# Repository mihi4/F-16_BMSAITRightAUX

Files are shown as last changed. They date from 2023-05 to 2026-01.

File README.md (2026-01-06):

# !!! ATTENTION !!!!
## I don't use BMSAIT anymore, so this repository is quite outdated and never got into my sim as it is

# BMSAIT Right Aux Controller
* Microcontroller: Arduino Nano

## Hardware controlled
- PFD
- CAUTION PANEL
- COMPASS
- FUEL QTY Gauge
- HYD PRESS Gauges
- EPU FUEL Gauge
- CABIN PRESS Gauge
- ~~(LIQUID FUEL Gauge)~~
- SIM1 Panel (??? 3 LEDs of MM5451 available)
## Pinmapping
* PFD: 
  * Serial Display  
    (Old DED, 2 pins, softwareSerial) D2,D3
* CAUTION PANEL:
  * 1 MM5451  
    (2 pins) D4,D5
* HYD PRESS:
  * 2 Servos  
    (2 pins) D6,D7
* FUEL QTY:
  * 2 servos  
    (2 pins) D8,D9
  * MAX7219 5 digit 7seg display  
    (3 pins) D10,D11,D12
* AX1201728SG (7 pins), D13-A5
  * COMPASS: 1 X27  
    (2 pins)
  * CABIN PRESS: 1 X27  
    (2 pins)
  * EPU FUEL: 1 X27  
    (2 pins)  
* Input for compass seroizing sensor (1 pin) A6  
* Input for compass seroizing button (1 pin) A7

## !!! Use those files at your own risk !!!

All the files are free to use under the GNUGPLv3

If you find those files useful and would like to support me with an icecream, coffee or pizza, you can use paypal.me to do so ;)  
[Paypal.me](https://paypal.me/MichiHirczy)

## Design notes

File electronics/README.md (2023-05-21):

# KiCAD files and other files related to electronics hardware

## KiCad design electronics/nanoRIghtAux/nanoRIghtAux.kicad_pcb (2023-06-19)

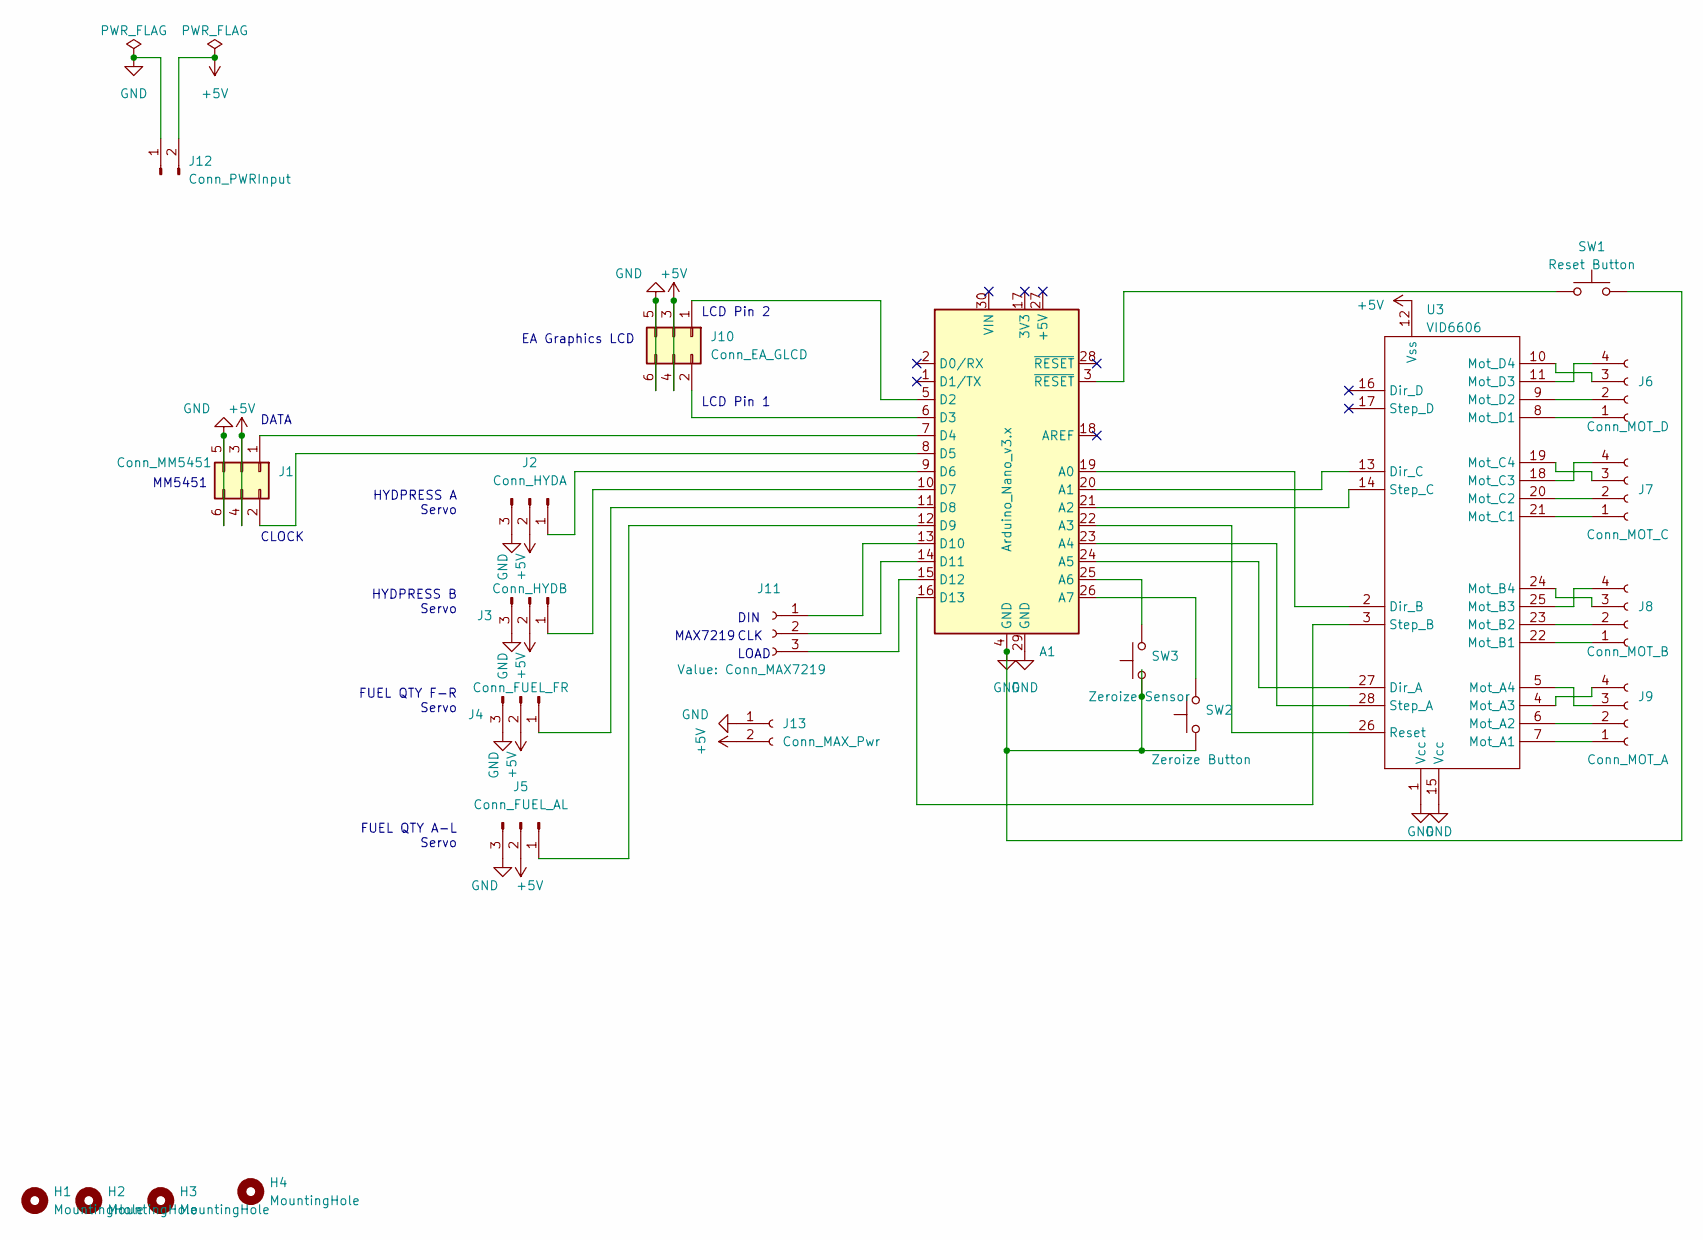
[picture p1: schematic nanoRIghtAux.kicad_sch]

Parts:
A1: Arduino_Nano_v3.x; Arduino_Nano
H1, H2, H3, H4: MountingHole; MountingHole_3.5mm
J1: Conn_MM5451; PinHeader_2x03_P2.54mm_Vertical
J2: Conn_HYDA; PinHeader_1x03_P2.54mm_Vertical
J3: Conn_HYDB; PinHeader_1x03_P2.54mm_Vertical
J4: Conn_FUEL_FR; PinHeader_1x03_P2.54mm_Vertical
J5: Conn_FUEL_AL; PinHeader_1x03_P2.54mm_Vertical
J6: Conn_MOT_D; PinHeader_1x04_P2.54mm_Vertical
J7: Conn_MOT_C; PinHeader_1x04_P2.54mm_Vertical
J8: Conn_MOT_B; PinHeader_1x04_P2.54mm_Vertical
J9: Conn_MOT_A; PinHeader_1x04_P2.54mm_Vertical
J10: Conn_EA_GLCD; PinHeader_2x03_P2.54mm_Vertical
J11: Conn_MAX7219; PinSocket_1x03_P2.54mm_Vertical
J12: Conn_PWRInput; PinHeader_1x02_P2.54mm_Vertical
J13: Conn_MAX_Pwr; PinSocket_1x02_P2.54mm_Vertical
SW1: Reset Button; PinHeader_1x02_P2.54mm_Vertical
SW2: Zeroize Button; PinHeader_1x02_P2.54mm_Vertical
SW3: Zeroize Sensor; PinHeader_1x02_P2.54mm_Vertical
U3: VID6606; DIP-28_W15.24mm

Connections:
+5V: J1.3, J1.4, J2.2, J3.2, J4.2, J5.2, J10.3, J10.4, J12.2, J13.2, U3.12 (Vss)
GND: A1.4 (GND), A1.29 (GND), J1.5, J1.6, J2.3, J3.3, J4.3, J5.3, J10.5, J10.6, J12.1, J13.1, SW1.2, SW2.1, SW3.1, U3.1 (Vcc), U3.15 (Vcc)
unnamed: A1.19 (A0), U3.2 (Dir_B)
unnamed: A1.20 (A1), U3.13 (Dir_C)
unnamed: A1.21 (A2), U3.14 (Step_C)
unnamed: A1.22 (A3), U3.26 (Reset)
unnamed: A1.23 (A4), U3.28 (Step_A)
unnamed: A1.24 (A5), U3.27 (Dir_A)
unnamed: A1.25 (A6), SW3.2
unnamed: A1.26 (A7), SW2.2
unnamed: A1.5 (D2), J10.1
unnamed: A1.6 (D3), J10.2
unnamed: A1.7 (D4), J1.1
unnamed: A1.8 (D5), J1.2
unnamed: A1.9 (D6), J2.1
unnamed: A1.10 (D7), J3.1
unnamed: A1.11 (D8), J4.1
unnamed: A1.12 (D9), J5.1
unnamed: A1.13 (D10), J11.1
unnamed: A1.14 (D11), J11.2
unnamed: A1.15 (D12), J11.3
unnamed: A1.16 (D13), U3.3 (Step_B)
unnamed: A1.3 (~RESET), SW1.1
unnamed: J6.1, U3.8 (Mot_D1)
unnamed: J6.2, U3.9 (Mot_D2)
unnamed: J6.3, U3.10 (Mot_D4)
unnamed: J6.4, U3.11 (Mot_D3)
unnamed: J7.1, U3.21 (Mot_C1)
unnamed: J7.2, U3.20 (Mot_C2)
unnamed: J7.3, U3.19 (Mot_C4)
unnamed: J7.4, U3.18 (Mot_C3)
unnamed: J8.1, U3.22 (Mot_B1)
unnamed: J8.2, U3.23 (Mot_B2)
unnamed: J8.3, U3.24 (Mot_B4)
unnamed: J8.4, U3.25 (Mot_B3)
unnamed: J9.1, U3.7 (Mot_A1)
unnamed: J9.2, U3.6 (Mot_A2)
unnamed: J9.3, U3.5 (Mot_A4)
unnamed: J9.4, U3.4 (Mot_A3)

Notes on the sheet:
LOAD
HYDPRESS A Servo
HYDPRESS B Servo
FUEL QTY F-R Servo
CLK
CLOCK
MAX7219
FUEL QTY A-L Servo
DATA
LCD Pin 2
LCD Pin 1
EA Graphics LCD
MM5451
DIN

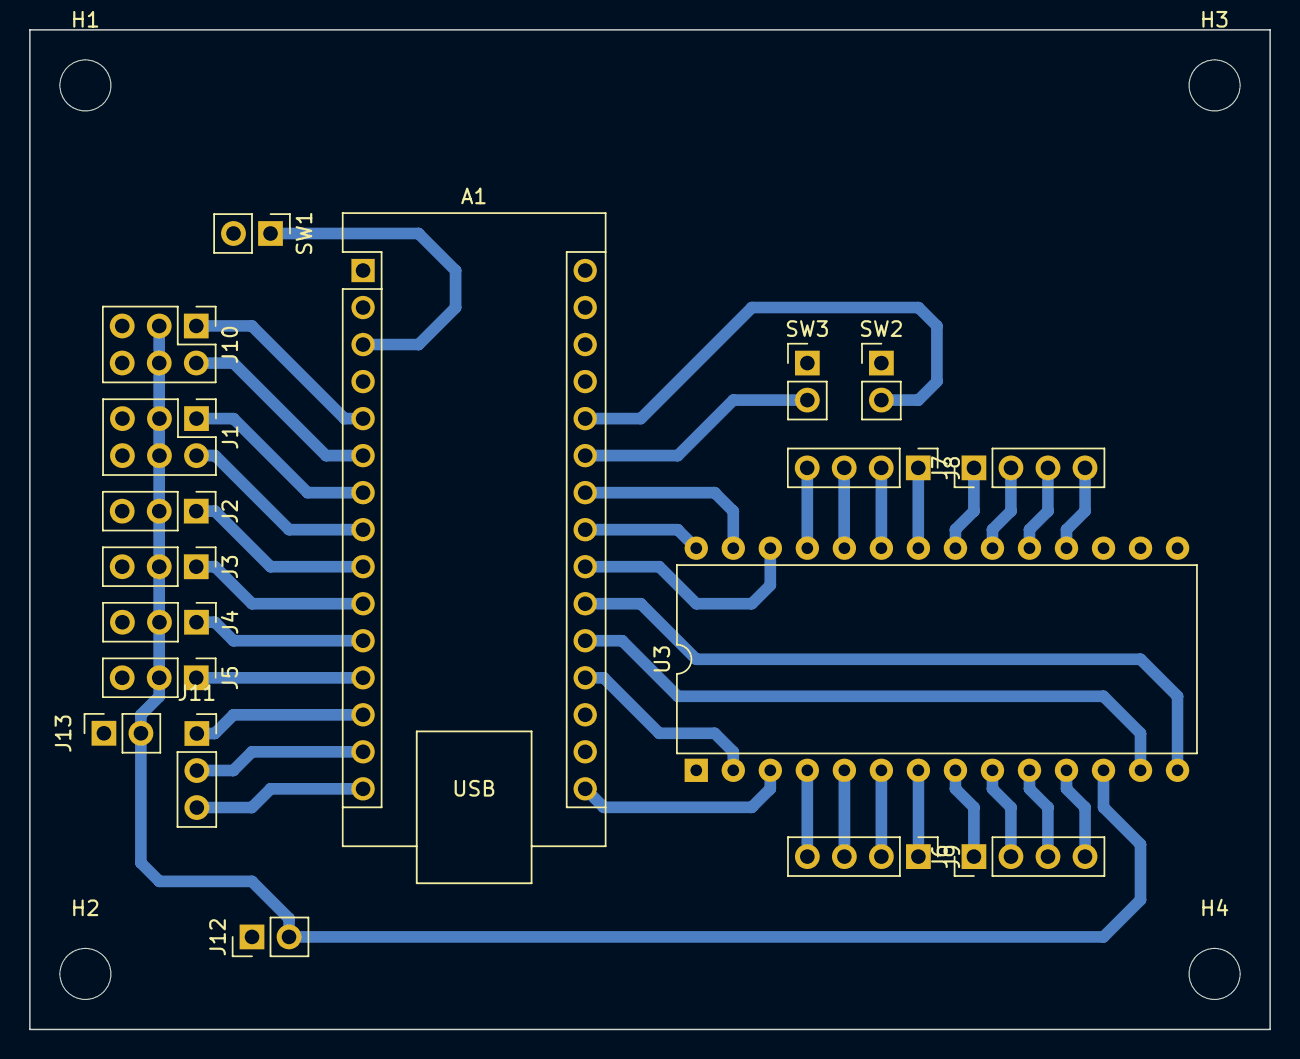
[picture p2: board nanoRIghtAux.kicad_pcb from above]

Board: 2 copper layers, 85.1 x 68.6 mm, 22 parts (0 on the bottom side), 39 nets.

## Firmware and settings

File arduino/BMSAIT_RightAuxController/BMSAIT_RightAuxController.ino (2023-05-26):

// Arduino sketch to send/recieve data from the Falcon BMS Shared Memory via the BMS-Arduino Interface Tool and control devices in home cockpits
// Version: 1.3.13   30.3.22
// Robin "Hummer" Bruns


//basic settings
  #include <Arduino.h>
  #include <OneButton.h>

  #define DATENLAENGE 8       // maximum length of a data set
  #define MESSAGEBEGIN 255    // this byte marks the beginning of a new message from the Windows app
  #define HANDSHAKE 128       // this byte marks an identification request from the Windows app
  #define SWITCHPOSITION 150  // this byte marks a request to send current switch positions
  #define CALIBRATE 160       // this byte marks a request to reset motors to inital position
  #define ZEROIZE   161       // this byte marks a request to fast zeroize motors 
  #define STARTPULL 170       // this byte marks a request to start the PULL logic on the arduino
  #define ENDPULL 180         // this byte marks a request to end the PULL logic on the arduino
  #define TESTON  190         // activates testmode
  #define READBACKON 191      // activates testmode with readback of data variables
  #define TESTOFF 200         // deactivates testmode
  #define VAR_BEGIN '<'       // char to mark the begin of the actual data
  #define VAR_ENDE '>'        // char to mark the end of the actual data
  #define TYP_ANFANG '{'      // char to mark the begin of the type definition in a message string
  #define TYP_ENDE '}'        // char to mark the begin of the type definition in a message string
  
//Function headers
  void ReadData();
  void UpdateInput();
  void UpdateOutput();
  void PullRequest(byte v);
  void ReadResponse();     
  void DebugReadback(byte posID);
  void SendSysCommand(const char text[]); 
  void SendMessage(const char message[], byte option);
  void ResetMotors();
  void FastUpdate();
  bool CheckForSysCommand(byte SysCmd);
  
  
  
//Struct definitions
  typedef struct //data field structure for storage of data variables
  {
    char bezeichnung[6];            //short description (max. 5 characters)
    char ID[5];                     //only required for PULL-operation. The ID for this data from "BMSAIT-Variablen.csv". this will tell the windows app what kind of data you are requesting
    char format;                    //only required for PULL-operation. Data type according to  "BMSAIT-Variablen.csv" (y=byte, i=integer, f=float, s=string, b=bool, 1=Byte Array, 2=Int Array, 3=string Array, 4=float Array) 
    byte typ;                       //indicates the type of device that will be used to output his data (10: LED, 20: LCD, 30: 7-Segment MAX7219, 40: Servomotor)
    byte target;                    //this byte links the variable to a specific device (i.e. PIN for LED output, the adress for motors on a pwm shield or to differentiate between multiple devices within one module)
    byte ref2;                      //the use of reference byte depends on the output type. Ref2 can set the line on LCD displays
    byte ref3;                      //the use of reference byte depends on the output type. Ref3 can set the length if a data value to display on LCD or 7-segment displays
    byte ref4;                      //the use of reference byte depends on the output type. Ref4 can set the position of data on LCD / 7Segment displays. if set, the data will be offset by this number of characters
    byte ref5;                      //the use of reference byte depends on the output type. Ref5 can mark the position of the decimal point on 7-Segment displays
    char request[10];               //precompiled pull request message
    char wert[DATENLAENGE];         //contains the current value
  } Datenfeld;

  typedef struct              //container to store incoming data from the Windows app
  {
    byte varNr;                     //position for this data in the local file container 
    char typ;                       //file format of this data 
    char wert[DATENLAENGE];         //data
  } Uebertragung;
  Uebertragung neuer_wert;

//Load user settings
  #include "BMSAIT_UserConfig.h"   //load the user settings 

//Global variables
  byte inputByte_0;           //container for incoming serial message
  byte inputByte_1;           //container for incoming serial message
  byte state =0;              //marker to memorize the current position in a message string
  byte Uebertragung_pos=0;    //counts how many chars have already been read from an incoming data stram. Used to prevent an overflow of data variables. 
  bool debugmode=false;        //debugmode on/off
  bool readbackmode=false;        //Readbackmode on/off
  unsigned long lastInput =0; //last successful transmission  
    
  int compassOffset = 0;
  
  #ifdef DUE_NATIVE
    #define SERIALCOM SerialUSB   //enable communication over the native port of the DUE
  #else
    #define SERIALCOM Serial      //standard serial connection
  #endif
  
//settings for PULL logic
  bool pull= false;           //flag that defines wether to use push or pull logic (true=pull ; false=push). Can be switched by commands of the F4SMExporter App
  long lastPoll=0;            //timestamp of the last data request during pull logic
  byte last_request=99;        //marker for the last variable that was requested via pull logic in the last loop 
//settings for PULL logic



//button matrix settings
#ifdef ButtonMatrix               
  #include "BMSAIT_Buttonmatrix.h"
#endif  

//analog axis settings
#ifdef AnalogAxis 
  #include "BMSAIT_Analogachse.h"
#endif 

//LED settings
#ifdef LED                             
  #include "BMSAIT_LED.h"
#endif

//LED matrix settings
#ifdef LEDMatrix                             
  #include "BMSAIT_LEDMatrix.h"
#endif

//LED MM5451 settings
#ifdef LED_MM5451
  #include "BMSAIT_LED_MM5451.h"
#endif

//LCD settings
#ifdef LCD                              
  #include "BMSAIT_LCD.h"
#endif    

//7Segment settings MAX 7219 tube
#ifdef SSegMAX7219                              
  #include "BMSAIT_SSegMAX7219.h"
#endif                                

//7Segment settings TM1637 tube
#ifdef SSegTM1637                            
  #include "BMSAIT_SSegTM1637.h"
#endif  

//DotMatrix settings SLx2016 tube
#ifdef SLx2016                            
  #include "BMSAIT_SLx2016.h"
#endif  

//Servo settings
#ifdef ServoMotor                       
  #include "BMSAIT_Servo.h"               
#endif                            

//PWM Shield for Servos settings
#ifdef ServoPWM                       
  #include "BMSAIT_ServoPWMShield.h"               
#endif  

//Steppermotor settings
#ifdef StepperBYJ                  
  #include "BMSAIT_Stepper28BYJ48.h"
#endif                                

//Steppermotor settings
#ifdef StepperX27                 
  #include "BMSAIT_StepperX27.h"
#endif  

//Steppermotor ControllerBoard settings
#ifdef StepperVID                   
  #include "BMSAIT_StepperVID.h"
#endif  

//Compass setting
#ifdef CompassX27                  
  #include "BMSAIT_CompassX27.h"
#endif  

//Compass setting
#ifdef AltimeterX27                  
  #include "BMSAIT_AltimeterX27.h"
  #include "AltimeterInternal.h"
#endif  

//switch and signal settings
#ifdef Switches                
  #include "BMSAIT_Switches.h" 
#endif  
 

//motor poti settings
#ifdef MotorPoti 
  #include "BMSAIT_MotorPoti.h"
#endif 

#ifdef OLED
  #include "BMSAIT_OLED.h"
#endif

#ifdef SpeedBrake                             
  #include "BMSAIT_SBI.h"
#endif

#ifdef FuelFlowIndicator
  #include "BMSAIT_FF.h"
#endif

#ifdef DED_PFL                             
  #include "BMSAIT_DED_PFL.h"
#endif

#ifdef Lighting                             
  #include "BMSAIT_Lighting.h"
#endif

//rotary encoders
#ifdef RotEncoder               
  #include "BMSAIT_Encoder.h"
#endif  


//example how to add your own project to this sketch. 
#ifdef NewDevice                
  #include "BMSAIT_Placeholder.h"
#endif  






//********************
//Main Program
//********************

///Setup of BMSAIT
void setup()
{
  SERIALCOM.begin(BAUDRATE);
	
  #ifdef LED                            //LEDs setup begin
    SetupLED();
  #endif                                //LEDs setup end
  
  #ifdef LEDMatrix                      //LEDMatrix setup begin
    SetupLEDMatrix();
  #endif                                //LEDMatrix setup end

  #ifdef LED_MM5451                      //LED MM5451 setup begin
    SetupLED_MM5451();
  #endif                                //LED MM5451 setup end
 
  #ifdef LCD                            //LCD setup begin
   SetupLCD();
  #endif                                //LCD setup end
  
  #ifdef SSegMAX7219                    //7-segment-display MAX7219 setup begin
   SetupMax7219();
  #endif                                //7-segment-display MAX7219 setup end

  #ifdef SSegTM1637                     //7-segment-display TM1637 setup begin
   SetupTM1637();
  #endif                                //7-segment-display TM1637 setup end

  #ifdef SLx2016                        //Dotmatrix-display SLx2016 setup begin
   SetupSLx2016();
  #endif                                //Dotmatrix-display SLx2016 setup end
                              
  #ifdef ServoMotor                     //servo setup begin
   SetupServo();
  #endif                                //servo setup end
  
  #ifdef ServoPWM                       //servo PWM shield setup begin
    SetupServoPWM();          
  #endif                                //servo PWM shield setup end
    
  #ifdef StepperBYJ                     //stepper setup begin
   //SetupStepperBYJ();
  #endif                                //stepper setup end

  #ifdef StepperX27                     //stepper setup begin
   SetupStepperX27();
  #endif                                //stepper setup end
  
  #ifdef StepperVID                     //stepper on controller board setup begin
   SetupStepperVID();
  #endif                                //stepper setup end

  #ifdef CompassX27                     //Compass setup start
   SetupCompassX27();
  #endif                                //Compass setup end

  #ifdef AltimeterX27                   //Altimeter setup start
   SetupAltimeterX27();
   SetupAltimeterKnob();
  #endif                                //Altimeter setup end

  #ifdef MotorPoti                      //MotorPoti setup begin
    SetupMotorPoti();
  #endif                                //MotorPoti setup end
  
  #ifdef OLED                           //OLED setup begin
    SetupOLED();
  #endif                                //OLED setup end
  
  #ifdef SpeedBrake                     //SBI setup begin
    SetupSBI();
  #endif                                //SBI setup end
  
  #ifdef FuelFlowIndicator              //FFI setup begin
   SetupFFI();
  #endif                                //FFI setup end
  
  #ifdef DED_PFL                        //DED setup begin
    SetupDED();
  #endif                                //DED setup end

  #ifdef Switches                       //Input controller setup begin
   SetupSwitches();
  #endif                                //Input controller setup end
  
  #ifdef ButtonMatrix                   //Buttonmatrix setup begin
   SetupButtonMatrix();
  #endif                                //Buttonmatrix setup end
  
  #ifdef RotEncoder                     //Rotary encoder setup begin
   SetupEncoder();
  #endif                                //Rotary encoder setup end

  #ifdef AnalogAxis                     //Analog axis setup begin
   SetupAnalog();
  #endif                                //Analog axis setup end  

  #ifdef Lighting                       //Lighting axis setup begin     
   SetupLighting();
  #endif                                //Lighting axis setup end 

  #ifdef NewDevice                      //Example. Use this placeholder to activate your own projects
    SetupNewDevice();
  #endif                                //Example end

 //precompile pull messages
  char pos[2]={0,0};
  char nachricht[10]={0};
  for (byte var=0;var<VARIABLENANZAHL;var++)
  {                                          
    itoa(var,pos,10);  //write data container position as character
    if (var<10) 
    {
      nachricht[0]='0'; 
      nachricht[1]=pos[0];
    }
    else 
    {
      nachricht[0]=pos[0]; 
      nachricht[1]=pos[1];
    }
    nachricht[2]=',';
    nachricht[3]=datenfeld[var].format;  //add the variable type
    nachricht[4]=',';
    for (byte lauf=0;lauf<4;lauf++)
      {nachricht[5+lauf]=datenfeld[var].ID[lauf];} //add the variable ID
    nachricht[9]='\0';
    strcpy(datenfeld[var].request,nachricht);
	SendMessage(datenfeld[var].request,1);
  }
  SendMessage("SETUP DONE",1);
  delay(1000);
}

/// Main loop
void loop()              
{	
  FastUpdate();
  delay(1);
  FastUpdate();
  ReadData();  //get new data from PC
  FastUpdate();
  UpdateOutput(); //update outputs (LEDs, motors, displays)  
  FastUpdate();
  UpdateInput(false); //check input devices (switches, buttons)
  FastUpdate();
}

//********************
//Functions
//********************

/// reset motor positions to default values
void ResetMotors(bool full)
{
#ifdef ServoMotor                       
  Servo_Zeroize(full);            
#endif                            

#ifdef ServoPWM                       
  ServoPWM_Zeroize(full);              
#endif  

#ifdef StepperVID
  StepperVID_Zeroize(full);   
#endif
 
#ifdef StepperX27
  StepperX27_Zeroize(full);  
#endif
 
#ifdef Stepper28BYJ48
  Stepper28BYJ48_Zeroize(full);  
#endif

#ifdef CompassX27
  CompassX27_Zeroize(full);
#endif 

#ifdef AltimeterX27
  AltimeterX27_Zeroize(full);
#endif 

#ifdef MotorPoti
  MotorPoti_Zeroize(full); 
#endif
}

///Call for another update of the motors to allow for fast, fluent movement
void FastUpdate()
{
#ifdef ServoMotor                       
  Servo_FastUpdate();            
#endif                            

#ifdef ServoPWM                       
  ServoPWM_FastUpdate();              
#endif 

#ifdef StepperVID
  StepperVID_FastUpdate();   
#endif
 
#ifdef StepperX27
  StepperX27_FastUpdate();  
#endif
 
#ifdef Stepper28BYJ48
  Stepper28BYJ48_FastUpdate();  
#endif 

#ifdef CompassX27
  CompassX27_FastUpdate();
#endif      

#ifdef AltimeterX27
  AltimeterX27_FastUpdate();
#endif      


#ifdef MotorPoti
  MotorPoti_FastUpdate(); 
#endif  
}

///check for fresh sharedMem data 
void ReadData()
{
	

  if (pull)  //send data requests if PULL mode is active
  {
    if (millis()-POLLTIME>lastPoll) //reduce the time between data request to prevent spamming (default POLLTIME 200 --> max of 5 attempts per second)
    {
      for (byte v=0;v<VARIABLENANZAHL;v++)  //request update of each data variable
        {PullRequest(v);}
      lastPoll=millis();
    }
  }   
  else  
  {
    while(SERIALCOM.available())
    { 
      #ifdef PRIORITIZE_OUTPUT
      UpdateOutput();   //throw in another update if outputs are priorized 
      #endif
      #ifdef PRIORITIZE_INPUT
      UpdateInput(false);   //throw in another update if inputs are priorized 
      #endif
      ReadResponse();   //check for new data from the windows app
    }   
    if (millis()-POLLTIME>lastPoll) //reduce the number of attempts to get new data (default POLLTIME 200 --> max of 5 attempts per second)
    {
      SendMessage("",5); // reqest new data
      lastPoll=millis();
    }       
  }
}


///loop through all data variables and update output devices
void UpdateOutput()
{
  #ifdef DED_PFL  
    UpdateDED();  
  #endif
 //SendMessage("updatingOutputs...",1);
 for (byte x=0;x<VARIABLENANZAHL;x++)     //loop through the data container. For each entry, the respective output will be updated
  {
	  //SendMessage(datenfeld[x].bezeichnung,1);
	  //SendMessage(datenfeld[x].wert,1);
    switch (datenfeld[x].typ)
    {
      #ifdef LED
        case 10: //LED (PIN is wired to GND)
          UpdateLED(x, true); 
          break;
        case 11: //LED (PIN is wired to Vcc)
          UpdateLED(x, false); 
          break;
      #endif 
            
      #ifdef LEDMatrix
        case 12: //LEDMatrix
          UpdateLEDMatrix(x); 
          break;
      #endif    

      #ifdef LED_MM5451
        case 13: //LED_MM5451
          UpdateLED_MM5451(x);
          break;
      #endif
      
      #ifdef LCD
        case 20: //LCD
          Update_LCD(x);
          break;
      #endif
        
      #ifdef SSegMAX7219 
        case 30:  //7-Segment display Max7219
          UpdateMAX7219(x);
          break;
      #endif
      
      #ifdef SSegTM1637
        case 31:   //7-Segment display TM1637
          UpdateTM1637(x);
          break;
      #endif

      #ifdef SLx2016
        case 32:   //7-Segment display TM1637
          UpdateSLx2016(x);
          break;
      #endif

      #ifdef ServoMotor
        case 40: //standard Servos (i.e. SG90)
          UpdateServo(x);
          break;
      #endif
      
      #ifdef ServoPWM  
        case 41: //Servo on PWM Shield
          UpdateServoPWM(x);
          break;
      #endif
      
      #ifdef StepperBYJ 
        case 50: //Stepper Motor
          UpdateStepperBYJ(x);
          break;
      #endif    
   
      #ifdef StepperX27
        case 51: //X27.168 directly connected to the arduino          
          UpdateStepperX27(x);
          break;
      #endif
    
      #ifdef StepperVID
        case 52: //one to four Servos on a VID6606 board
          UpdateStepperVID(x);
          break;
      #endif

      #ifdef CompassX27
        case 53: //compass driven by X-class stepper motor
          UpdateCompassX27(x);
          break;
      #endif
	  
	  #ifdef AltimeterX27
        case 54: //altimeter needle driven by X-class stepper motor
          UpdateAltimeterX27(x);
          break;
      #endif
	  
      
      #ifdef MotorPoti
        case 60: //MotorPoti
          UpdateMotorPoti(x);
          break;      
      #endif

      #ifdef OLED
        case 70: //generic OLED
          UpdateOLED(x);
          break;      
      #endif
      
      #ifdef SpeedBrake
        case 71: //Speedbrake OLED
          UpdateSBI(x);
          break;      
      #endif
      
      #ifdef FuelFlowIndicator
        case 72: //FFI OLED
          UpdateFFI(x);
          break;      
      #endif
      
      #ifdef Lighting
        case 80: //Backlighting
          UpdateLighting(x);
          break;      
      #endif
      
      #ifdef NewDevice  //define this flag in the top of BMSAIT_UserConfig.h to activate this block ("#define newDevice")
        case 69: //assign this type to a variable in the data container to call a new method
          UpdateNewDevice(x);  //program a new method void Update_newDevice(int p){command1;command2;...}to enable your device 
        break;
      #endif

      default:
        //not implemented
        break;
    }
  }  
}


void UpdateInput(bool all)
{
  #ifdef Switches              
   CheckSwitches(all);            //check switch positions and initiate commands if switches were moved
  #endif
                                 
  #ifdef ButtonMatrix         
   ButtonMatrixRead();         //check button matrix for changes and initiate commands if switches were moved 
  #endif
  
  #ifdef RotEncoder              
   CheckEncoder();            //check encoders and initiate commands if they were moved
  #endif
  
  #ifdef AnalogAxis      
   ReadAnalogAxis(all);           //check analog axis for changes and initiate commands if switches were moved
  #endif
  
  #ifdef AltimeterX27
	UpdateAltimeterKnob();
  #endif
  
}


///Send a message to the BMSAIT App to request an update for a data variable
void PullRequest(byte var)
{
  if(SERIALCOM.available())  //make sure input buffer is empty   
  {
    delay(1);
    FastUpdate();
    ReadResponse();
  }
    
    SendMessage(datenfeld[var].request,2);
	//if(debugmode){SendMessage(datenfeld[var].request,1);}
    byte x=0;
    while ((SERIALCOM.available()<3) && (x<PULLTIMEOUT)) //wait for answer, but no longer than 30ms
    {
      #ifdef PRIORITIZE_OUTPUT
        UpdateOutput(); //throw in another update if outputs are priorized
        x+=10;
      #endif
      #ifdef PRIORITIZE_INPUT
        UpdateInput();   //throw in another update if inputs are priorized
        x+=10;
      #endif
      delay(1);
      FastUpdate();
      x++;  
    }
    while(SERIALCOM.available()>1)  //read incoming data     
    {
      delay(1);
      FastUpdate();
      ReadResponse();
    }
}


void Reset()
{
  while (SERIALCOM.available()){SERIALCOM.read();}
  SendMessage("",5); // reqest new data
  state=0;
}
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

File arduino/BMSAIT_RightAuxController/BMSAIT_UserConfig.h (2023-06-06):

// Version: 1.3.11    30.3.22



//MODULE SELECTION - uncomment the modules you want to use.
   
  #define LED               //drive LEDs
  //#define LEDMatrix         //drive LED Matrix using a MAX7219 controller
  //#define LCD               //drive LCD display
  //#define SSegMAX7219       //drive 7-Segment displays via MAX7219 controller
  //#define SSegTM1637        //drive 7-Segment displays via TM1367 controller
  #define ServoMotor        //drive servo motors directly connected to the arduino
  //#define ServoPWM          //drive multiple servo motors via pwm shield
  //#define StepperBYJ        //drive stepper motor 28BYJ-48
  //#define StepperX27        //drive stepper motor X27.168
  //#define CompassX27        //drive a compass with a Xxx.xxx -class stepper motor
  //#define StepperVID        //drive multiple stepper motors X25.168 with a VID66-06 controller
  //#define MotorPoti         //motor-driven poti control
  //#define OLED              //display data on an OLED display
  //#define SpeedBrake        //Enable display of the SpeedBrake indicator on an 128x64 OLED display (DEDunino)
  //#define FuelFlowIndicator //Enable display of the FuelFlow indicator on an 128x64 OLED display (DEDunino)
  //#define DED_PFL           //Enable display of DED or PFL on an 254x64 OLED display (DEDunino)
  //#define Switches          //use the arduino to read switch positions and send keyboard commands
  //#define ButtonMatrix      //use the arduino to read switch positions and send keyboard commands
  //#define RotEncoder        //use the arduino to read rotary encoders and send keyboard commands
  //#define AnalogAxis        //use the arduino to read analog resistors and sync this with a gamecontroller axis
  //#define Lighting          //software controlled backlighting
  //#define NewDevice         //placeholder. Use this line to activate your own code to drive other, specific hardware



//BASIC SETTINGS
  #define BAUDRATE 57600      // serial connection speed
  #define POLLTIME 200           // set time between PULL data requests
  #define PULLTIMEOUT 30      // set time to wait for a requested data update defaut: 30ms
  #define PRIORITIZE_OUTPUT    //uncomment this to put a stress on fast update of outputs (should be used for motors to allow smoother movements)
  //#define PRIORITIZE_INPUT     //uncomment this to put a stress on fast er poll of inputs (switches/Buttons) 
  const char ID[]= "BMSAIT_RightAuxController"; //Set the ID for this arduino program. Use any string. The program will use this ID to check in with the BMSAIT windows application

  
//BOARD SELECTION

  //#define UNO         //uncomment this if this sketch will be loaded on an UNO
  #define NANO        //uncomment this if this sketch will be loaded on an NANO
  //#define MICRO       //uncomment this if this sketch will be loaded on an MICRO
  //#define LEONARDO    //uncomment this if this sketch will be loaded on an LEONARDO
  //#define MEGA        //uncomment this if this sketch will be loaded on an MEGA
  //#define DUE         //uncomment this if this sketch will be loaded on an DUE (connected via programming port)
  //#define DUE_NATIVE  //uncomment this if this sketch will be loaded on an DUE (connected via native port)
  //#define ESP         //uncomment this if this sketch will be loaded on an ESP32 or ESP8266
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

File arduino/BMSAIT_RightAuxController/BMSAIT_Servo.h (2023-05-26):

// settings and functions to drive servo motors (directly connected to the arduino)
// V1.3.7 26.09.2021

//target= reference link to the line of the servodata table of this module
//ref2= not used
//ref3= not used
//ref4= not used
//ref5= not used

#include <Servo.h>

#define SERVODELAY 80
#define SERVOSLEEPTIME 20000

typedef struct
{
byte pIN;           //PIN the motor is connected to
byte p_ug;          //min arc for the motor (must not be less than 0!)
byte p_og;          //max arc for the motor (must not be more than 180!)
long a_ug;           //min absolut value that might be displayed (i.e.   0 for a speed indicator)
long a_og;           //max absolut value that might be displayed (i.e. 800 for a speed indicator)
long last;           //previous value
unsigned long lu;   //last update
} Servodata;


Servodata servodata[] =
{// pIN  p_ug  p_og  a_ug  a_og  last  lu
	{6,   180,   0,   1,   65535,    0,   0}, 	// HYDPRESS A
	{7,   180,   0,   1,   65535,    0,   0}, 	// HYDPRESS B
	/*{8,   0,   180,   1,   65535,    0,   0},  	// FUEL QTY Fwd
	{9,   0,   180,   1,   65535,    0,   0}  	// FUEL QTY Aft
    
	{A1,   0,   180,   0,   800,    0,   0},  // example speed indicator: {Servo on PIN=9, min arc =0, max arc=180, lowest possible value=0, highest value=800, past value=0, lastUpdate=0}
	{11,   0,   90,   0,   1,    0,   0},  // PNEU Flag
	{12,   0,   180,   0,   65535,    0,   0},  // KIAS	
	{13,   0,   180,   0,   20,    0,   0},  // mach
	{A1,   40,   140,   -170,  170,    0,   0},  // VVI usually -100 to 100; default value uses just -170 to 170 for values of -1.0 to 1.0
    {A2,   0,   90,   0,   1,    0,   0},  // vvi data2
	{A3,   0,   180,   -350,   350,    0,   0},  // AOA  -35 to 35 deg; float value, see above
	{A4,   0,   90,   0,   1,    0,   0}  // AOA Flag  */
};
const int SERVOZAHL = sizeof(servodata)/sizeof(servodata[0]);
Servo servo[SERVOZAHL];

void SetupServo()
{  
  for (byte lauf=0;lauf<SERVOZAHL;lauf++)
  {
    servo[lauf].attach(servodata[lauf].pIN);
    servo[lauf].write(servodata[lauf].p_ug);
    delay(500);
    servo[lauf].write(servodata[lauf].p_og);
    delay(500);
    servo[lauf].write(90);
    delay(500);
	servo[lauf].write(servodata[lauf].p_ug);
	delay(100);
    servo[lauf].detach();
  }
}

void Servo_FastUpdate()
{}

void Servo_Zeroize(bool mode)
{
  for (byte lauf=0;lauf<SERVOZAHL;lauf++)
  {
    if (!servo[lauf].attached())
        {servo[lauf].attach(servodata[lauf].pIN);}  //reactivate servo
    servo[lauf].write(servodata[lauf].p_ug);
    if (mode)
    {
      delay(500);
      servo[lauf].write(servodata[lauf].p_og);
      delay(5000);
      servo[lauf].write(servodata[lauf].p_og - servodata[lauf].p_ug);
      delay(5000);
    }
	servo[lauf].write(servodata[lauf].p_ug);
	delay(100);
    servo[lauf].detach();
  }
}


void UpdateServo(byte id)
{	

	/*if (debugmode){SendMessage("updatingServo",1);}
	if (debugmode){SendMessage(datenfeld[id].ID,1);}
	if (debugmode){SendMessage(datenfeld[id].wert,1);}  */

  if (servodata[datenfeld[id].target].lu + SERVOSLEEPTIME < millis())
  {
    servo[datenfeld[id].target].detach();                        //disable servo if no new signal for more than 5 seconds
  }  
  else if (servodata[datenfeld[id].target].lu + SERVODELAY < millis())
  {
    servodata[datenfeld[id].target].lu = millis();  //pause servo
    
	long newValue = 0;
	if (datenfeld[id].format == 'f') { 
		float tmpVal = atof(datenfeld[id].wert);
		newValue = tmpVal * 10;
	} else {
		newValue = atol(datenfeld[id].wert);
	}
    if (servodata[datenfeld[id].target].last != newValue)
    {	  
	  uint16_t winkel;
      servodata[datenfeld[id].target].last = newValue; 
      if (!servo[datenfeld[id].target].attached())
        {servo[datenfeld[id].target].attach(servodata[datenfeld[id].target].pIN);}  //reactivate servo      
	  winkel = map(servodata[datenfeld[id].target].last, servodata[datenfeld[id].target].a_ug, servodata[datenfeld[id].target].a_og, servodata[datenfeld[id].target].p_ug, servodata[datenfeld[id].target].p_og); 
	  servo[datenfeld[id].target].write(winkel);          
    }
  }
}

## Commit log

2023-05-21 changed directory names of BMSAIT controllers
    [nanoRIghtAux.kicad_pcb, nanoRIghtAux.kicad_sch]
2023-05-23 Update BMSAIT_LED_MM5451.h, BMSAIT_RightAuxController.ino, and 13 more files...
2023-06-06 added builtin LED for some tests
2023-06-09 added builtin led fo status display atm
2023-06-14 started adding connectors
    [nanoRIghtAux.kicad_sch]
2023-06-14 removed servos, connectors only
    [nanoRIghtAux.kicad_sch]
2023-06-14 exchanged all parts with connectors
    [nanoRIghtAux.kicad_pcb, nanoRIghtAux.kicad_sch]
2023-06-14 connectors renamed
    [nanoRIghtAux.kicad_sch]
2023-06-14 changed 2x03 connector type
    [nanoRIghtAux.kicad_sch]
2023-06-14 PCB edit started
    [nanoRIghtAux.kicad_pcb, nanoRIghtAux.kicad_sch]
2023-06-14 PWR input pinheader added, MAX7219_PWR pinheader added, PCB routing changed
    [nanoRIghtAux.kicad_pcb, nanoRIghtAux.kicad_sch]
2023-06-14 first routing of TH components done.
    [nanoRIghtAux.kicad_pcb, nanoRIghtAux.kicad_sch]
2023-06-14 routing cleanup of TH components
    [nanoRIghtAux.kicad_pcb]
2023-06-14 first gerber/echelon outputs
    [nanoRIghtAux-B_Cu.gbr, nanoRIghtAux-B_Silkscreen.gbr, nanoRIghtAux-NPTH.drl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]
2023-06-14 Flatcam Project started
    [nanoRIghtAux-job.gbrjob]
2023-06-14 mountingholes addes
    [nanoRIghtAux.kicad_pcb, nanoRIghtAux.kicad_sch]
2023-06-15 changed footprint of AX12 to DIP28
    [nanoRIghtAux.kicad_pcb, nanoRIghtAux.kicad_sch]
2023-06-15 changed pin assignments for AX12 to facilitate routing
    [nanoRIghtAux.kicad_pcb, nanoRIghtAux.kicad_sch]
2023-06-15 new routing started, 12mm hole for placint GX12 connector added
    [nanoRIghtAux.kicad_pcb]
2023-06-15 structure cleanup
    [nanoRIghtAux-B_Cu.gbr, nanoRIghtAux-F_Cu.gbr, nanoRIghtAux-NPTH.drl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]
2023-06-15 text on frontside added
    [nanoRIghtAux.kicad_pcb]
2023-06-15 more routing added
    [nanoRIghtAux.kicad_pcb, nanoRIghtAux.kicad_sch]
2023-06-15 routing done
    [nanoRIghtAux.kicad_pcb, nanoRIghtAux.kicad_sch]
2023-06-15 first routing finished, exported Gerbers/Drillfiles
    [nanoRIghtAux.kicad_pcb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]
2023-06-15 updated pcb, added 12mm hole to user drawings layer
    [nanoRIghtAux-B_Cu.gbr, nanoRIghtAux-F_Cu.gbr, nanoRIghtAux-User_Drawings.gbr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]
2023-06-19 Update nanoRIghtAux-B_Cu.gbr, nanoRIghtAux-Edge_Cuts.gbr, and 6 more files...
    [nanoRIghtAux.kicad_pcb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]
2023-06-19 first fully completed pcb workflow
    [nanoRIghtAux.kicad_pcb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]
2023-06-19 layer changes
    [nanoRIghtAux.kicad_pcb]
